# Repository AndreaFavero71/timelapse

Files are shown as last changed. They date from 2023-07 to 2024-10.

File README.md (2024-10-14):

# Timelapse system with Raspberry Pi 4b and PiCamera V3 (wide)

#### timelapse system based on Raspberry Pi 4b and PiCamera V3 wide

The Picamera V3 has interesting characteristics, like auto-focus and HDR;<br />
It comes with Horizontal field of view (102 degrees) or normal (66 degrees), eventually without IR filter (noIR version).<br />
My choice went for the wide version, to have a larger FoV.<br />
<br /><br />

## Purpose
My intention has been documenting the people approaching my CUBOTino booth, at Hannover Maker Faire 2023.<br />
Anyhow, by testing the system on sunrise and sunset, I was already rewarded by this project.<br />

https://github.com/AndreaFavero71/timelapse/assets/108091411/2fbdf898-6a90-448d-a211-95300df74fcc

Hannover Maker Faire 2023: [2 days in 2 minutes](https://youtu.be/wAfPYTDUh8o)<br />
Sunrise and sunset [examples](https://youtu.be/wO7wYDtcbZA)<br />

<br /><br /><br /><br />

## 3D print cover with the camera support
The timelapse system has connection for tripod:<br />
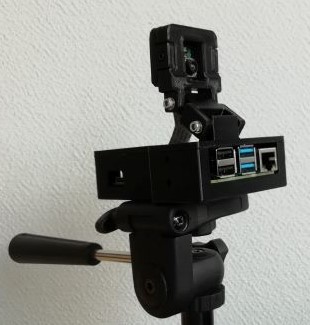
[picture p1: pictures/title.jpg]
title image
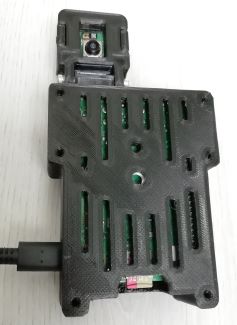
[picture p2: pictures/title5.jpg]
title image
   <br />

and adjustable camera orientation with storage for the camera ribbon cable:<br />
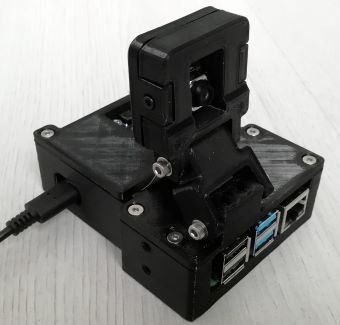
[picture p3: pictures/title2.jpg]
title image
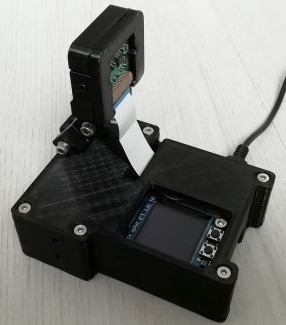
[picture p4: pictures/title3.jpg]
title image
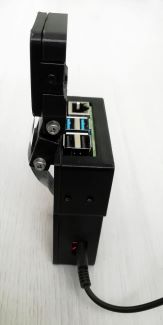
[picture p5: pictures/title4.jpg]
title image
     
<br /><br />
The camera is supported via an arm to vary its orientation, when not used on a tripod with moving head.<br />
Two holes at the cover sides can be used for other fixing systems (i.e. for brackets with suction caps to suspend the system on a window).<br />
Stl file are available at folder [/stl](/stl/).<br /><br /><br />

## Installation
For the installation the needed steps are listed in the [installation file](/setup/installation_steps.txt).
<br /><br /><br /><br />

## How it works
The overall idea is to predefine the job, let it go, and collect the assembled movie once the job is done.<br />
The system is based on a python script and a text file for the settings (the only file to be edited).<br /><br />

The [settings.txt](settings.txt) file includes:
- shooting start (hh:mm).
- shotting stop (hh:mm).
- interval between shoots (seconds).
<br /><br />

Other options are:
- Start shooting immediately (true/false).
- VNC preview (true/false).
- Camera resolution.
- HDR (High Dinamic Range) function at camera (true/false).
- Erasing older pictures from the microSD card that includes emptying the Wastebasket (true/false); This is done at the starting of a new job.
- Auto video generation after the shooting (true/false); this can be based on:
  - predefined fps (frame per second value.
  - predefind video time (in seconds), and the fps will be consequently adapted; For this choice fix_movie_t (true/false) and movie_time_s (seconds).
- Number of shooting days (integer), for the period defined by start and stop time.
- Folder name where saving the pictures and generating the movie.
- Usage of the display at Raspberry Pi (true/false).
- Some parameters for the display, like width, height, horizontal and vertical shif, orientation.<br />

### Notes:
1. Boolean variables can be set as true/false or 1/0 or yes/no or.... .<br />
2. In case the movie is not sattisfactory: Via the script video_render.py the video can be (re)made by changing some parameters. For this reason, the pictures aren't automatically erased after a job completion; pictures are automatically erased at the start of a new job.<br />
3. I found convenient to share a Raspberry Pi folder via SMB protocol, allowing quick access via a pc. For this reason, the pictures_folder is generated in the shared folder. The [installation file](/setup/installation_steps.txt) gives instructions also for this function.

A resume picture of the setting is available [here](https://github.com/AndreaFavero71/timelapse/blob/main/pictures/settings.png) <br />
More info at [instructable page of this project](https://www.instructables.com/Timelapse-With-Raspberry-Pi-4b-and-PiCamera-V3-wid/) <br />
<br /><br /><br /><br />

## Usage:
1. Switch on the Raspberry Pi.<br />
2. Connect to it; If you want a camera preview, a remote desktop connection is necessary like VNC Viewer.<br />
3. The relevant files are into the timelapse folder: ```cd timelapse```<br />
4. Edit the settings.txt file (quite self explanatory) and set the parameters according to your needs: ```nano settings.txt``` (save the file, with Ctrl + X, followed by Y, followed by Enter)<br />
5. Run the script: ```python timelapse.py``` (changes at the settings are only loaded at the scrip start). Arguments can be passed.<br />
6. The code defaults to V2 camera. If you use the V3 camera, add v3_camera argument: ```python timelapse.py --v3_camera```

Feedbacks on the display:<br />
- At the start it shows the main settings, including an estimation of pictures quantity the microSD can store<br />
- Time left for the first picture<br />
- After the first picture is taken, it indicates the picture progressive number<br />
- After the last picture is taken, if set, it indicates the video editing status<br />

In case the movie is not sattisfactory: Via the script video_render.py the video can be (re)made by changing some parameters. For this reason, when set, the pictures aren't automatically erased after a job completion; pictures are automatically erased at the start of a new job.<br />
By pressing one of the buttons for 5 seconds the cycle is stopped<br />
By pressing one of the buttons for more than 10 seconds the script is quitted; If the automating shut-off is set, this is the way to safely close stuff before unpowering the Raspberry Pi.<br />
<br /><br /><br /><br />

## Different methods defining the shooting approach:<br />
1) Shooting predefined between start_hhmm and stop_hhmm, for one or multiple days:<br />
- Set start_now as False and local_control as False.<br />
- Set start_hhmm and stop_hhmm to define the shooting period.<br />
- This method ends automatically, once the stop_hhmm of the last day is reached.<br /><br />

2) Shooting starting once the script is launced (eventually automated at the Raspberry Pi boot), and lasting for the period_hhmm:
- Set start_now as True and local_control as False.<br />
- Set period_hhmm to define how long the shooting period should last.<br />
- Also in this case the pictures quantity are predefined.<br />
To extend the shooting over days, weeks, etc, more than 2 digits can be set at the hours of period_hhmm (i.e. set '1000:30' to shoot for 1000 hours and 30 minutes).<br /><br />

3) By manually starting and pausing the shooting, eventually multiple times, via the buttons on the display:
- Set local_control as True.
- In this case the pictures quantity aren't predefined.
In all cases:
  - The interval between shots is defined by interval_s
  - A long press (>10 secs), of one of the buttons, will terminate the shooting and the script.

<br /><br /><br /><br />

## Automatic script starting at Boot
1. Edit the crontab: sudo crontab -e
2. Add at the end:
```
@reboot /bin/sleep 5; bash -l touch /home/pi/timelapse/timelapse_terminal.log && chmod 777 &_
```
```
@reboot /bin/sleep 5; bash -l /home/pi/timelapse/timelapse_bash.sh > /home/pi/timelapse/timelapse_terminal.log 2>&1
```
3. Save and exit: Ctrl + X, followed by Y, followed by Enter.<br />

After Raspberry Pi boots, the timepse.py script will be excuted according to parameters saved at [settings.txt](settings.txt) file.<br />
Note: To prevent the script from executing at boot, edit the crontab, comment out the two commands and save.
<br /><br /><br /><br />

## Recovery from power outage
This is especially relevant when the system is used for long periods, and power outage might happens. <br />
1. Set the automatic scrip to start at Boot. <br />
2. Set "date_folder" : "False" <br />
3. Set "erase_pics" : "False" <br />

After the power outage, Raspberry Pi boots and the code checks for the latest picture suffix as reference for the next new picture.<br />
In case of multiple days shooting, the days already covered by shooting (partially or fully) are counted (full days without power are also counted). Counted days are detracted from the total days set in settings, to complete the shooting as per schedule.
<br /><br /><br /><br />

## Shooting when enough illuminance
The illuminance estimation by the camera can be used to avoid shooting if illuminance is below a threshold. <br />
1. Set "lux_check" : "True"   (Default is False). <br />
2. Set "lux_threshold" : "30" (30 is about the illuminance at sunset/sunshine. Check [Wikipdia](https://en.wikipedia.org/wiki/Illuminance) for values reference. <br />

When "lux_check" is set False the code doesn't check the illuminance estimation by the camera. <br />
When "lux_check" is set True, and illuminance drops below "lux_threshold", the pictures aren't taken. In this case less pictures are saved while the shooting schedule is safeguarded. <br />
As example of "lux_threshold": "30":<br />
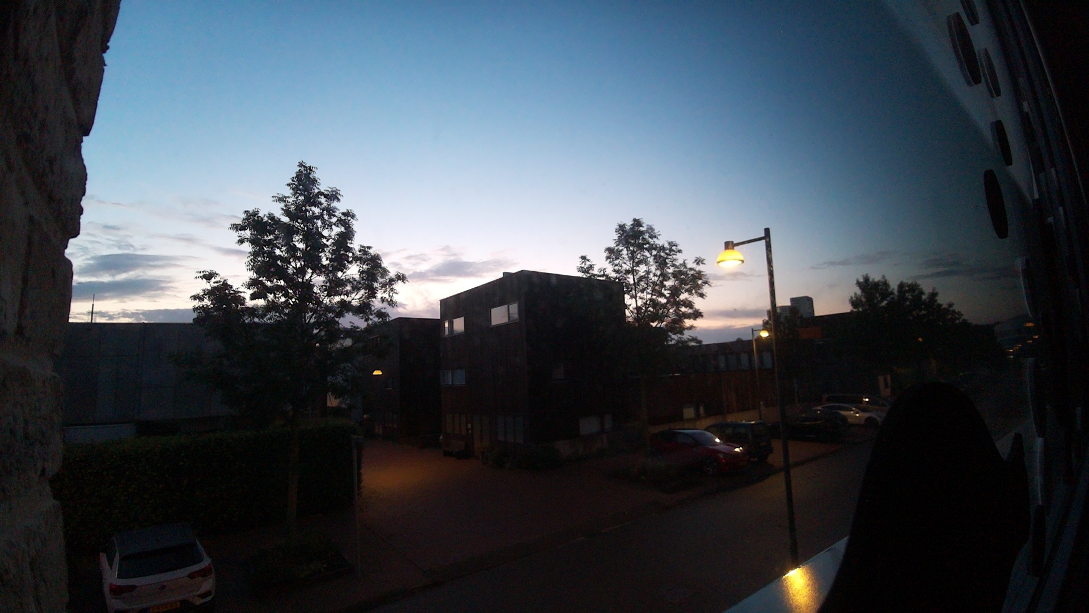
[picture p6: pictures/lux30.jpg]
  <br />
Make your own check on which threshold fits your setup.
 <br /><br /><br /><br />

## Parts
Total cost of the project is ca 130€ (plus shipments) <br />
- 1x [Raspberry Pi 4b](https://www.raspberrypi.com/products/raspberry-pi-4-model-b/) (ca 59€) <br />
- 1x [Picamera V3 Wide](https://www.raspberrypi.com/products/camera-module-3/) (ca 42€) <br />
- 1x [Power supply](https://www.raspberrypi.com/products/type-c-power-supply/) (ca 10€) <br />
- 1x [Display Mini PI TFT 1.3"](https://www.aliexpress.com/item/1005001746881831.html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) (ca 5€ at Aliexpress.com) <br />
- 1x microSD V30 32Gb or higher (ca 10€) <br />
- Screws (see [screws list](/stl/screws_list.txt)) <br />
- Filament for the 3D printer <br />
<br /><br /><br />

## More info:
A resume picture of the setting is available [here](https://github.com/AndreaFavero71/timelapse/blob/main/pictures/settings.png) <br />
More info at [instructable page of this project](https://www.instructables.com/Timelapse-With-Raspberry-Pi-4b-and-PiCamera-V3-wid/) <br />
<br /><br /><br />

## Possible improvements
1. Increase and improve feedback via the display (it's still quite under used).
2. I'm open for your suggestions.
<br /><br /><br />

## Credits and references
[Carolin Dunn](https://github.com/carolinedunn/timelapse/tree/master) tutorial on timelapse.<br />
[Daniel Kendell](https://www.youtube.com/watch?v=ofozNWdIDow) tutorial on overlapping text with ffmpeg.<br />
[TroubleChute](https://www.youtube.com/watch?v=8QxJWW0mjAs) tutorial for Raspberry Pi folder sharing via SMB protocol.<br />
[ffmpeg documentation](https://ffmpeg.org/documentation.html).<br /><br />

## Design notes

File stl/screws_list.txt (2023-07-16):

Timelapse: List of screws, nuts, washers

1x 1/4"-20 UNC  (nut with thread for tripods, to press into the hexagonal slot at the Base, see "Nut_at_Base.jpg" at /pictures)
4x M2.5x5mm (Raspberry Pi to Base)
4x M3x14mm cylindrical head (Arm to Base and camera-support to Arm, see "M3_nuts_washers.jpg" at /pictures)
4x M3 nuts (Base and Arm, see "M3_nuts_washers.jpg" at /pictures)
8x Washers for M3 (in between Arm to Base, between camera-support to Arm, underneath M3 bolts, see "M3_nuts_washers.jpg" at /pictures)
2x M2.5x4mm (Camera_cover to Camera_support)
1x M3x8mm cylindrical head (as display foot, see "display_foot1.jpg" and "display_foot2.jpg" at /pictures)
2x M3 nuts (as display foot, see "display_foot1.jpg" and "display_foot2.jpg" at /pictures)
3x Washers for M3 (underneath the external nut, see "display_foot1.jpg" and "display_foot2.jpg" at /pictures)
6x M3x8mm conical head (Cover to Base)

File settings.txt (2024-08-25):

{
"preview": "False",
"erase_pics": "True",
"erase_movies": "True", 

"local_control": "False",
"start_now": "True",
"period_hhmm": "01:00",
"start_hhmm": "10:00",
"end_hhmm": "12:00",
"interval_s": "20",
"days": "1",

"rendering": "True",
"fix_movie_t": "True",
"movie_time_s": "20",
"fps": "24",
"overlay_fps": "False",
"overlay_text": "",

"camera_w": "1920",
"camera_h": "1080",
"hdr": "True",
"autofocus": "True",
"focus_dist_m": "0.1",
"lux_check": "False",
"lux_threshold": "30",
"date_folder": "True",
"folder": "timelapse_pics",
"parent_folder": "/home/pi/shared",
"pic_name": "picture",
"pic_format": "jpg",
"rotate_180": "False",

"display": "True",
"modified_disp": "False",
"disp_preview": "False",
"disp_image": "False",
"disp_rotation": "90",
"disp_bright": "100",
"disp_width": "240",
"disp_height": "240",
"disp_offsetL": "0",
"disp_offsetT": "0"
}

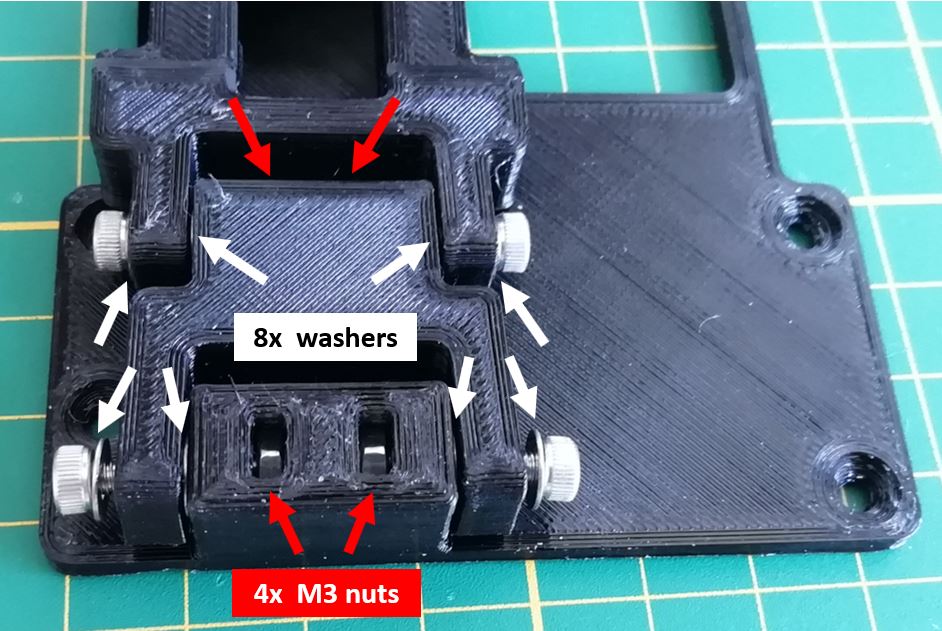
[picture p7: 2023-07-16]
pictures/M3_nuts_washers.jpg

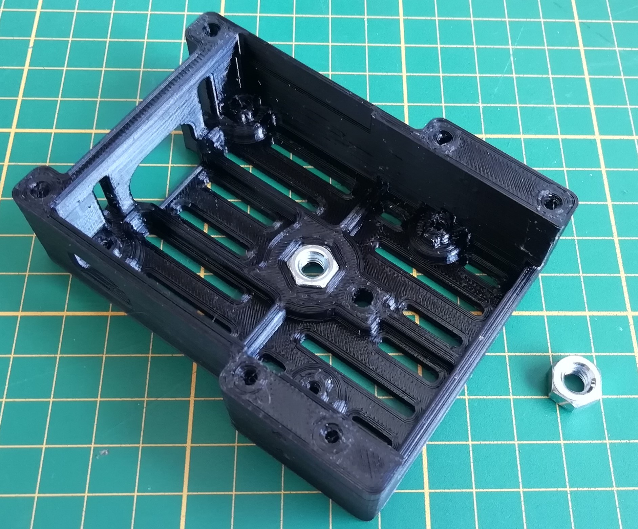
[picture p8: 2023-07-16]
pictures/Nut_at_Base.jpg

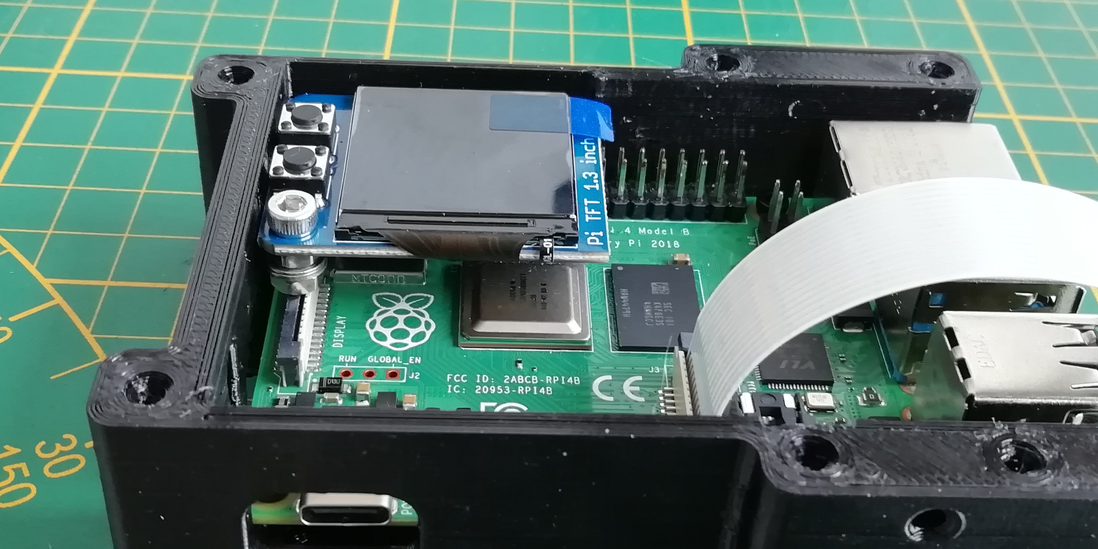
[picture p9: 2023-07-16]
pictures/display_foot2.jpg

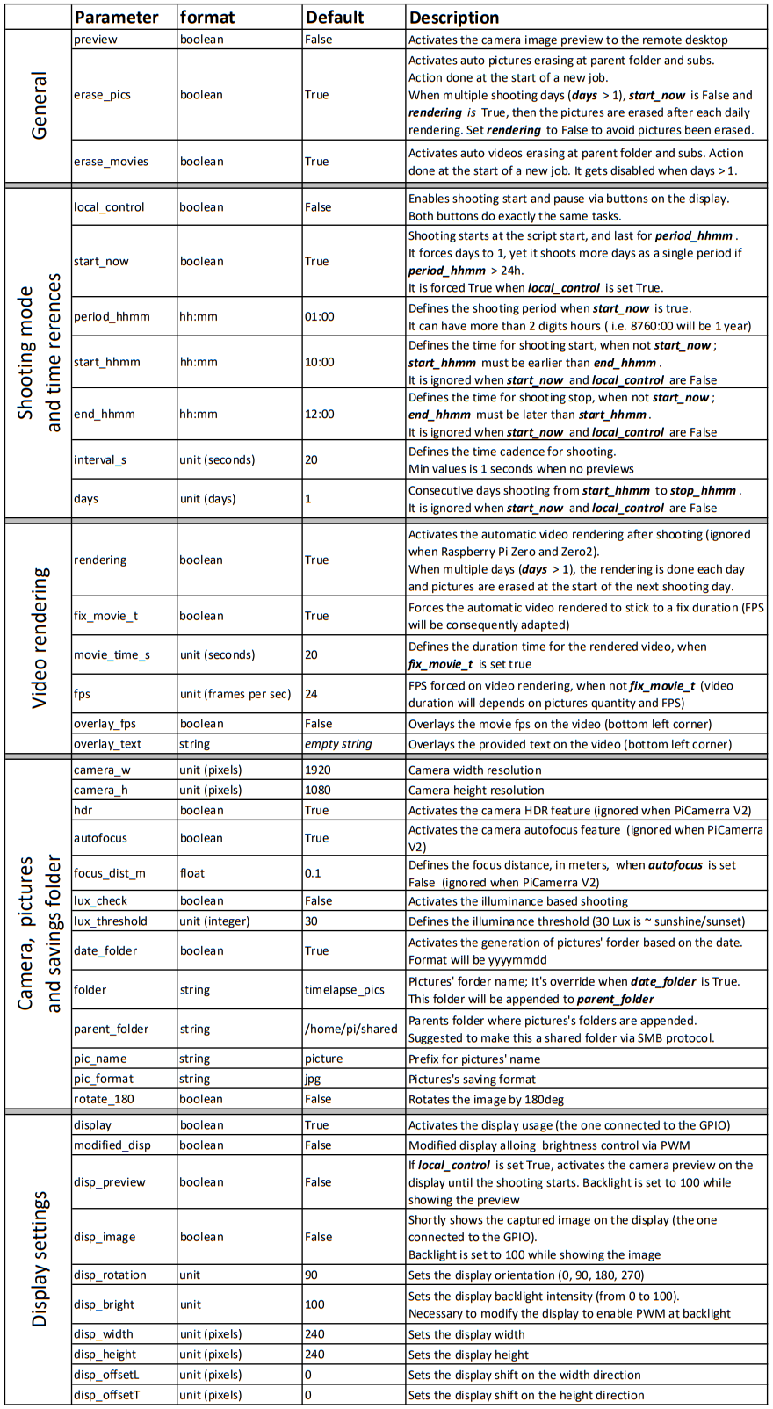
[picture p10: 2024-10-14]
pictures/settings.png

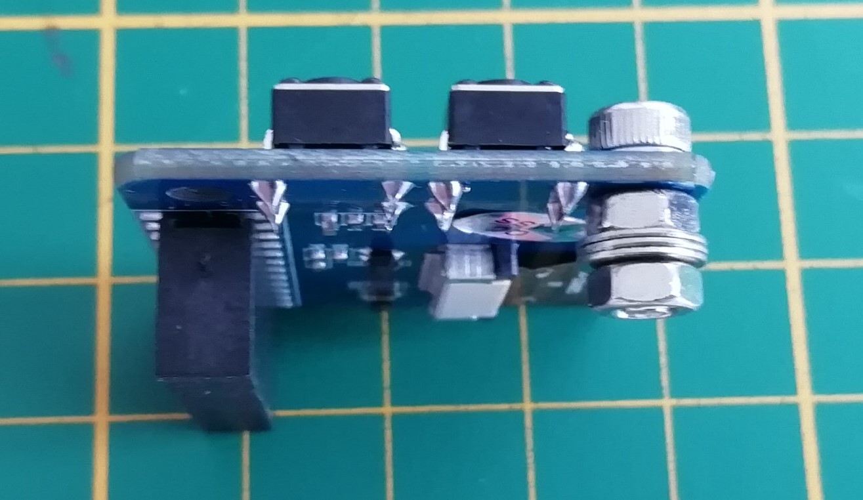
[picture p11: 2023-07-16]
pictures/display_foot1.jpg

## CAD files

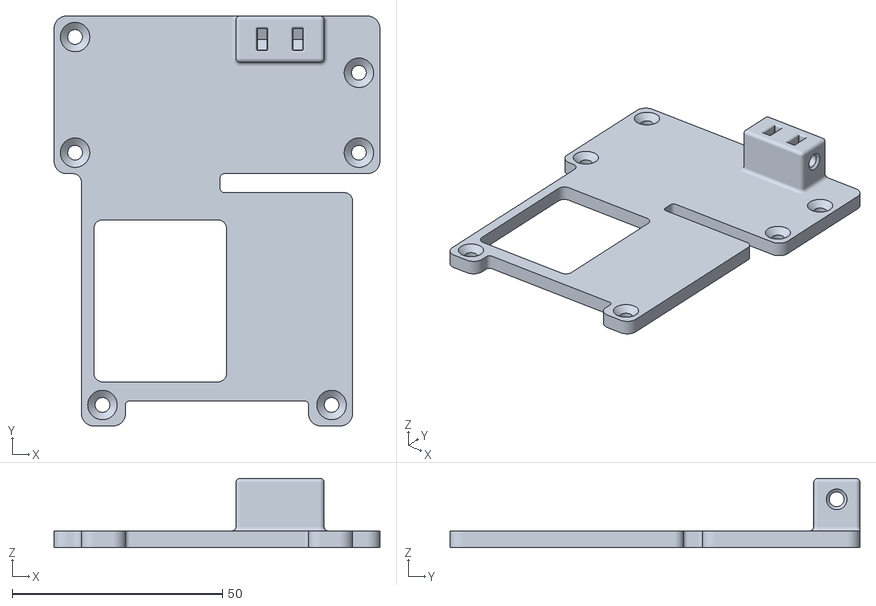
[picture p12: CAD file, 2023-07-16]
stl/Cover.stl
77.5 x 97.5 x 16.5

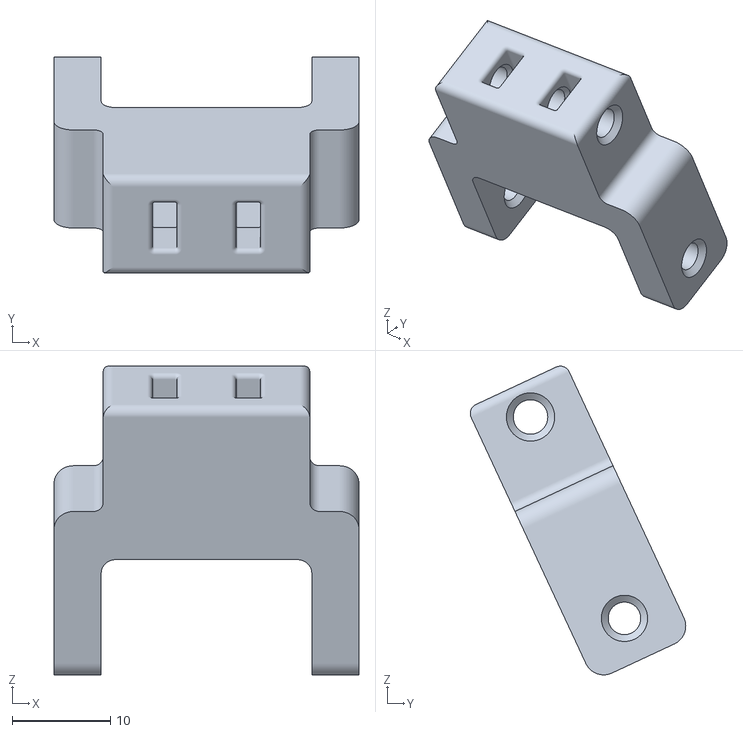
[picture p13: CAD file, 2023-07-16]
stl/Arm.stl
31.0 x 21.9 x 31.4

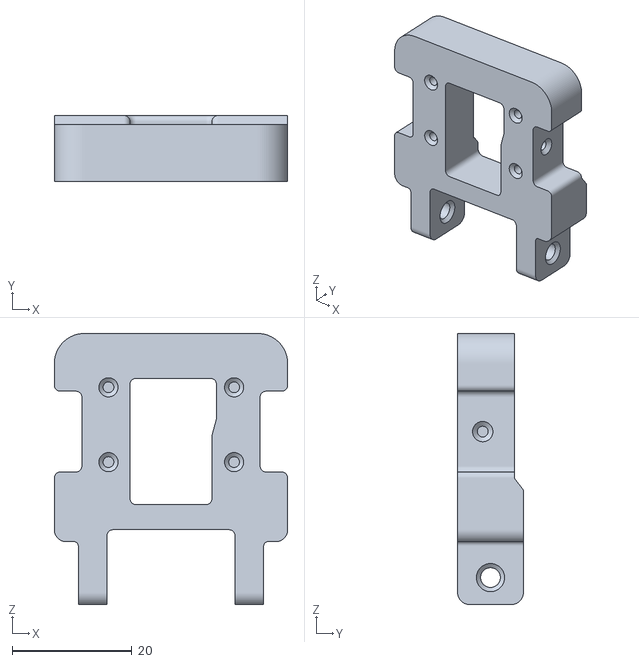
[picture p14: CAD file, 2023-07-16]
stl/Camera_supp.stl
39.0 x 11.0 x 45.3

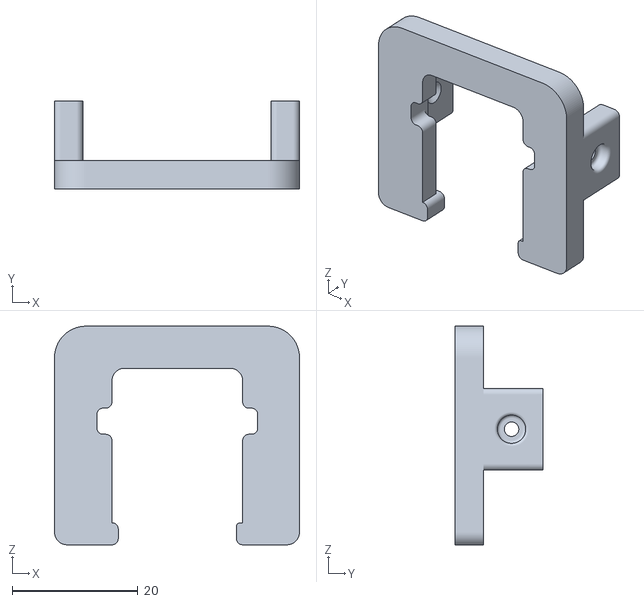
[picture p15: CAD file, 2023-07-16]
stl/Camera_cover.stl
39.0 x 14.0 x 34.8

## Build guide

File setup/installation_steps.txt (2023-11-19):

Setting up the Timelapse:
1. Flash bullseye OS (32 bit) in a fast (V30) microSD card, via Raspberry Pi Imager or other imager tool.
1.1 It is convenient to set a meaningfull Hostname (i.e. timelapse).
1.2 For convenience with the script, leave Username as "pi", while you're invited to set your own password (do not use the raspberry as password).
1.3 Configure the LAN from which you're going to initially connect (i.e. via SSH).
2. Into the boot folder copy the wpa_supplicant.conf text file with included the wi-fi connections you might need (phone AP is a convenient one); An example of this file if provided as reference, to be personalized with your Country digits, the Wi-Fi SSID and Passwords.
3. Into the boot folder make an empty text file named ssh (without extention).
4. Insert the microSD into the Raspberry Pi, power on and wait until the green LED stops blinking.
5. Check for the Raspberry Pi IP in your network.
6. Connect to the Raspberry Pi via SSH (i.e. via Putty).
7. Update the system: sudo apt update
8. Upgrade the system: sudo apt upgrade -y
9. Install the picamera library (it should be already installed): sudo apt install python3-picamera2
10. Install the driver for the display: sudo pip3 install ST7789==0.0.4
11. Enable the SSH, SPI, VNC and VNC Display resolution: sudo raspi-config
11.1 Select: Interface Options
11.2 Select: SSH   (then YES)
11.3 Select: Interface Options
11.4 Select: SPI   (then YES)
11.5 Select: Interface Options
11.6 Select: VNC   (then YES)
11.7 Select: Display Options
11.8 Select: VNC Resolution (choose the one tha better suit your PC monitor, then OK)
11.9 Select: Finish
11.10. Confirm the reboot with YES (if you miss it, from the terminal type: sudo reboot)
12. Connect via VNC (i.e. via realVNC)
13. Open the Terminal (this step can be done from step 7)
14. Clone the repository: git clone https://github.com/AndreaFavero71/timelapse.git (this step can be done from step 7)

Making a shared folder via SMB protocol:
1. Install samba; From the Terminal: sudo apt install samba samba-common-bin (confirm with y, and yes at DHCP package wins)
2. Make the folder to share: mkdir /home/pi/shared
3. Edit samba config file: sudo nano /etc/samba/smb.conf    (at the file end add the below 6 rows, Ctrl + Ins to paste)
[shared]
path=/home/pi/shared
writeable=yes
create mask=0777
directory folder=07777
pubblic=no
4. Save and close the samba config file: Ctrl+X then Y then Enter
5. Associate your username: sudo smbpasswd -a pi    (pi is the username)
   once requested enter your password (the one to access the Raspberry Pi)
   once requested enter your password again (the one to access the Raspberry Pi)
   at this point there should be a confirmation "Added user pi."
6. Restart smb service: sudo systemctl restart smbd
7. Get the Raspberry Pi IP: hostname -I  (capital I)
8. On your File Explorer Adress bar paste the IP, after the prefix "\\" and followed by the postfix "\shared": \\xx:xx:xx:xx\shared
9. Enter the password, and check it to get memorized.
10. The Raspberry Pi "shared" folder should be visible as a network folder; map it as a drive for convenience.

Test / usage
1. The timelapse files are under 'timelapse' folder: cd timelapse
2. Edit the settings.txt file, set it for a couple of minutes shooting, and save it: nano settings.txt  (Ctrl + X  then Y  then Enter)
3. Run the timelapse script: python3 timelapse.py
4. If the preview is enabled, an additional windows opens with the Picamera preview live streaming.
5. Check into the generated folder at /home/shared/  for the captured pictured and the generated timelapse movie.

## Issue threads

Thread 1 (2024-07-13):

Error and fix to use a Picamera V2 instead of V3

mharmuth, 2024-07-13:
First of all: Thank you for this great project!

I got a little error when trying to execute the script. I've got a Raspberry Pi4 Model B with the Pi camera module V2.
`python3-pycamera2` is installed and working (I tested it with an example script from the project).

But when I try to run your script, I get the following log
```
pi@pios:~/timelapse $ python3 timelapse.py

Processor architecture: aarch64

[1:17:28.995680973] [5916]  INFO Camera camera_manager.cpp:313 libcamera v0.3.0+65-6ddd79b5
[1:17:29.021947286] [5919]  WARN RPiSdn sdn.cpp:40 Using legacy SDN tuning - please consider moving SDN inside rpi.denoise
[1:17:29.023584068] [5919]  WARN RPI vc4.cpp:392 Mismatch between Unicam and CamHelper for embedded data usage!
[1:17:29.024210767] [5919]  INFO RPI vc4.cpp:446 Registered camera /base/soc/i2c0mux/i2c@1/imx219@10 to Unicam device /dev/media4 and ISP device /dev/media1
[1:17:29.024254303] [5919]  INFO RPI pipeline_base.cpp:1104 Using configuration file '/usr/share/libcamera/pipeline/rpi/vc4/rpi_apps.yaml'
[1:17:29.026548765] [5916]  INFO Camera camera_manager.cpp:313 libcamera v0.3.0+65-6ddd79b5
[1:17:29.051271480] [5922]  WARN RPiSdn sdn.cpp:40 Using legacy SDN tuning - please consider moving SDN inside rpi.denoise
[1:17:29.052839967] [5922]  WARN RPI vc4.cpp:392 Mismatch between Unicam and CamHelper for embedded data usage!
[1:17:29.053406703] [5922]  INFO RPI vc4.cpp:446 Registered camera /base/soc/i2c0mux/i2c@1/imx219@10 to Unicam device /dev/media4 and ISP device /dev/media1
[1:17:29.053443869] [5922]  INFO RPI pipeline_base.cpp:1104 Using configuration file '/usr/share/libcamera/pipeline/rpi/vc4/rpi_apps.yaml'
[1:17:29.060032979] [5916]  INFO Camera camera.cpp:1183 configuring streams: (0) 1920x1080-XBGR8888 (1) 640x360-YUV420 (2) 1920x1080-SRGGB10_CSI2P
[1:17:29.060428680] [5922]  INFO RPI vc4.cpp:621 Sensor: /base/soc/i2c0mux/i2c@1/imx219@10 - Selected sensor format: 1920x1080-SRGGB10_1X10 - Selected unicam format: 1920x1080-pRAA
unknown control 'wide_dynamic_range'
  HDR setting returned an error

Failing to close the Picamera
Failing to clean the display
Failing to set low the GPIO pin 22
Traceback (most recent call last):
  File "/home/pi/timelapse/timelapse.py", line 1183, in <module>
    variables, error = setup()             # retrieves settings, and initializes things
                       ^^^^^^^
  File "/home/pi/timelapse/timelapse.py", line 256, in setup
    picam2, camera_started, error = set_camera(camera_w, camera_h, rotate_180, hdr, autofocus, focus_dist_m, preview)
    ^^^^^^^^^^^^^^^^^^^^^^^^^^^^^
TypeError: cannot unpack non-iterable float object

During handling of the above exception, another exception occurred:

Traceback (most recent call last):
  File "/home/pi/timelapse/timelapse.py", line 1185, in <module>
    exit_func(error)                       # exit function is caleld
    ^^^^^^^^^^^^^^^^
  File "/home/pi/timelapse/timelapse.py", line 1134, in exit_func
    if display:
       ^^^^^^^
NameError: name 'display' is not defined
```

Here is my `settings.txt`:
[settings.txt](https://github.com/user-attachments/files/16202125/settings.txt)

I don't know what the error can be. Maybe you can help ;-)

AndreaFavero71, 2024-07-13:
This code has been writtren for the Picamera V3.
The camera V2 does't have some of features of the V3 model, like autofocus and HDR, and errors are generated when trying to set the parameters for those features.

A possible fix:
1) at timelapse.py comment out rows from 334 to 343 included.
2) set false the parameters autofocus and HDR in the settings.txt (as per yourr current settings).
.... and the script will be compatible with the V2 camera (I have just tried).

Please be aware:
1) the PiCamera V2 has fix focus, that can only be manually adjusted.
2) the HDR is really a worth feature, especially when the subject is partially shadowed.
Of course it depends from your application, if the autofocus (that also means you can set a fix focus to a given distance via the settings) and the HDR are usefull or not.

mharmuth, 2024-07-15:
Hi @AndreaFavero71,

thanks for your help. I can confirm that it's working with the rows commented out. Thanks again!

But I will go and grab the PiCamera V3 to have the additional features.

Closed 2024-07-15.

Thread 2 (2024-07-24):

Construction Cam

weedy171, 2024-07-24:
Love the project. Not really an issue, but wondering if you have any suggestion in setting it up so it only records during the daylight between sunrise and sunset. I would like to use your project for a small construction project that is going to last about 3 months.

Thanks !

AndreaFavero71, 2024-07-26:
Hi, the code Is not linked with a calendar, therefore it isn't possible to start shooting at sunrise and stop at sunset.
The code accepts a start time, a stop time, and eventually the number of days to repeat the shooting between start and stop.
During the construction, I would recommend to approach the Raspberry Pi from time to time, and discharge the pictures or the video clips. This to backup the data, preventing total loss in case of a any issue, for instance the microSD getting corrupted.

weedy171, 2024-07-28:
Appreciate the suggestions. I did find a script that will look at images and determine if they are black. I think I am having some trouble though with my settings. I am hoping to set my timelapse to run every day and take a picture at 600 seconds for three months. I was thinking about rebooting the device nightly as well(or might change it to the week) Thinking about recovery if a power outage was to occur and where it could pick up where its at.

{
"preview": "False",
"erase_pics": "False",
"erase_movies": "False",

"local_control": "False",
"start_now": "True",
"period_hhmm": "01:00",
"start_hhmm": "00:01",
"end_hhmm": "23:59",
"interval_s": "600",
"days": "120",

"rendering": "False",
"fix_movie_t": "False",
"movie_time_s": "20",
"fps": "24",
"overlay_fps": "False",
"overlay_text": "",

"camera_w": "1920",
"camera_h": "1080",
"hdr": "True",
"autofocus": "True",
"focus_dist_m": "0.1",
"date_folder": "True",
"folder": "timelapse_pics",
"parent_folder": "/home/weedy/shared",
"pic_name": "picture",
"pic_format": "jpg",
"rotate_180": "False",

"display": "True",
"modified_disp": "False",
"disp_preview": "False",
"disp_image": "False",
"disp_rotation": "90",
"disp_bright": "100",
"disp_width": "240",
"disp_height": "240",
"disp_offsetL": "0",
"disp_offsetT": "0"
}

AndreaFavero71, 2024-07-28:
Hi, getting the code starting automatically at the boot is rather easy, I'll follow up.
The current code is not meant to restart from where it left, but it makes a lot of sense in case of power outage.
Once back from holiday I'll  modify the code.
When is the construction going to start?
When will you have the setup ready for testing?

Considering the expected large variation of light condition, strongly suggested a camera with HDR function, so the V3 normal or the V3 wide.

Also recommended to set a couple of wifi addresses at the Raspberry Pi, one of them with your laptop hotspot (Windows allows it if the PC has a wifi connection, that could be to your phone hotspot)

For the settings, there is a bit more explanation  at the Instructables project [page](https://www.instructables.com/Timelapse-With-Raspberry-Pi-4b-and-PiCamera-V3-wid/).
Considering your scope, I'd set start_hhmm when the daily activities are expected to start, let say 0700. Similarly, the stop__hhmm when the daily activities are supposed to stop, let say 1900.
I'd also reduce the interval_s to 300 seconds, and eventually double the frames per second of the video clip, for a smoother result. Total quantity of images are still manageable, so the memory.
I have a few more notes about settings, but those will come later

weedy171, 2024-07-29:
Thanks again for your replies.
My construction project is starting the end of next month. I was starting to play around with it to get a feel for the size of pictures and how often I would need to get grab them and how well it would work on recovery of power loss if their was any(don’t have a way to put a UPS outside)

I am using this camera https://www.adafruit.com/product/5658 -- I tried a higher resolution 4608 × 2592 pixels but it was not happy about that.

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

AndreaFavero71, 2024-07-29:
Hi, that camera supports the HDR (strongly suggested to use it) by reducing the resolution to the HD format. Depending on the subject, the JPG file might take from 250Kb (large uniform areas) to 600Kb (small uniform areas).
I believe, by mid of August, I'll be able to add the info for the automatic start after booting, and the code change to proceed with pictures' names from where it was before an eventual power outage....

weedy171, 2024-08-08:
Thanks for looking into this while you are on holiday. I updated the latest py and updated my settings to the following. I noticed it created the folder "timelapse_pics" inside my shared but don't see any pictures in it. I was able prior to get the autostart the py while and the old py was generating images.

{
"preview": "True",
"erase_pics": "False",
"erase_movies": "False",

"local_control": "False",
"start_now": "False",
"period_hhmm": "8760:00",
"start_hhmm": "06:00",
"end_hhmm": "19:00",
"interval_s": "180",
"days": "120",

"rendering": "False",
"fix_movie_t": "False",
"movie_time_s": "20",
"fps": "24",
"overlay_fps": "False",
"overlay_text": "",

"camera_w": "1920",
"camera_h": "1080",
"hdr": "True",
"autofocus": "True",
"focus_dist_m": "0.1",
"date_folder": "False",
"folder": "timelapse_pics",
"parent_folder": "/home/weedy/shared",
"pic_name": "picture",
"pic_format": "jpg",
"rotate_180": "False",

"display": "False",
"modified_disp": "False",
"disp_preview": "False",
"disp_image": "False",
"disp_rotation": "90",
"disp_bright": "100",
"disp_width": "240",
"disp_height": "240",
"disp_offsetL": "0",
"disp_offsetT": "0"
}

AndreaFavero71, 2024-08-08:
Hi, when the code is started at the boot (crontab), all the prints will be
saved in the text file timelapse_terminal.log.

Everytime the Raspberry Pi boots, the same file will be used (over written)
Please boot the system again, and check the content of that file within the
expected shooting period of the day.
In case or errors indications, share the complete file to
***@***.***
Perhaps good to share it anyhow.

I'm going to be driving the coming days, therefore I'll be rather limited
... yet good for me to start thinking what goes grong and why.

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

weedy171, 2024-08-08:
I just checked this morning and it started taking pictures at the start period.  I will have to play with it later in the day to see if a reboot of the device makes it still work.

weedy171, 2024-08-09:
I think I figured it out, I had the end time set earlier in the night compared to when i was working on the script. It appears to be working. I will play around with it some more. Do you think the resolution I have set could be any better or you think that is good for the Camera 3?

AndreaFavero71, 2024-08-09:
Hi, sounds good.
1920x1080 is the max resolution for the V3 camera, when HDR is set True.
The video clip will be HD.
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
AndreaFavero71, 2024-08-15:
Hi, after a power outage, the code is started automatically at the boot, and if you reconnect to the Raspberry Pi you won't see the prints made by code to the terminal ... yet prints are redirected to a text file: /timelapse/timelapse_terminal.log (this is what I meant as "terminal.log file").
So you can open that text file, to see what kind of feedback the code is printing out, further than checking the timestamp of the pictures in folder.

Be aware the boot takes a couple of minutes and the first picture will be taken at about the next minute chance; When waiting, without doing anything lse, this time seems even longer and it might let you think the code not being active ....
Having the mini display on the Raspberry Pi makes life easier :-)

On the tests I performed, everything was working fine.
Overall, I have hard time to follow the chain of events at your end, I'm afraid it requires more detailed and clear info from you.

weedy171, 2024-08-16:
Thanks for the replies. I was playing around with it tonight and doing a couple of power outage simulations and do not see the same results like I reported prior. I haven’t had a chance to play around with the daylight setting. I might just leave it alone. I plan on checking the camera at least once a week and grab the pictures and feel comfortable with what I have setup. Appreciate the code fix and the contributions for this project. I know some linux stuff but I am not around it lot, so its fun to play around this stuff too.

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

AndreaFavero71, 2024-08-21:
Hi, I think I've discovered the reason we have different results after recovering from a power outage.
Background: The timing methd used to take the pictures is based on the EPOCH time, to prevent shifting over time.
In my case, once the Pi boots it will also find a network and an NTP (Network Time Protocol) and this might not be always the case or your case.
When the Pi boots and does not find a NTP, the internal clock proceeds from where it left: The pictures won't be taken as per intended schedule.

To overcome this issue, I see two options:
1) Adding a RTC module, with backup battery, to the the Pi (i.e. search for 'DS3231 Real Time Clock Module RTC Clock Memory Module 3.3V/5V for Raspberry Pi').
2) Changing the shootting approach (settings) to "start_now": "True" with a very long period "period_hhmm": "3000:00"  (covers 125 days) and by bounding the shooting to the illuminance level.

**Option 1** is rather clean yet, further than the hardware, it requires to properly set the Pi in order to use the hardware clock after a power outage. Time alignment with NTP happen once the Pi will connect to a network. I don't have personal experience with these modules. With this option the pictures time stamp are always correct.

**Option 2** should work too, yet with some caviets. In case of power outage and booting without a network available (no NTP), the pictures will be tken as per interval_s and Lux but the timestamp will be wrong.

I have now available a Pi with a screen alowing for tests with and without network connection: Tests on option 2 confirms the above notes.

weedy171, 2024-08-21:
I just installed the device last night and noticed the issue of the time changing and I had to manually set it. I will find out in a couple days how things are going.

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

AndreaFavero71, 2024-08-25:
Hi, I've just released an update, that includes:
1) Recovering from power outage also when the shooting approach is based on "start_now" and related "period_hhmm".
2) Moved the "lux_check" and "lux_threshold" to the settings.txt.
3) Some minor improvements.
Wrt your target, I think you'll benefit from setting "start_now" as True, a very long "period_hhmm" (i.e 3000:00 will cover 125 days) and by bounding the shooting to the illuminance level: Set "lux_check" as True and "lux_threshold" to 30.
In case the system is not into a network nor having a RTC module, by setting "start_now" as True and the illuminance control, the shooting  schedule won't mess up in case a power outage will happen.

weedy171, 2024-08-27:
I was able to grab three days worth prior to the start of the construction and everything looked great. Then it appeared it worked for a day after then stopped. I missed two important destruction so kinda bummed about that. Not sure what happened. I tried to implement some of your suggestions below and now I did not see it try to take pictures after a reboot. Can you look at the settings I posted above and make sure I am not missing anything. Do you think because I am not rendering the file that is an issue?

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

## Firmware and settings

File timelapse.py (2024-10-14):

#!/usr/bin/python
# coding: utf-8

"""
#############################################################################################################
#  Andrea Favero 10 October 2024,
#  Timelapse module, based on Raspberry Pi 4b and PiCamera (V2 or V3)
#
#  Last version (addition): Recovery from power outage and shooting when illuminance above threshold
#  Recovery from power outage works when below parameters are set like:
#        "date_folder" : "False" (it points to "folder")
#        "erase_pics" : "False"  (latest picture suffix retrieved to prevent pictures being overwritten)
#  Shooting when illuminance above threshold works when below parameters are set like:
#        "lux_check" : "True"    (it enables lux estimation by the camera)
#        "lux_threshold" : "30"  (sets the lux threshold, 30 is about the illuminance at sanset/sunshine)
#############################################################################################################
"""


# __version__ variable
version = '0.7 (10 Oct 2024)'


################  setting argparser for parameter parsing  ######################################
import argparse

# argument parser object creation
parser = argparse.ArgumentParser(description='CLI arguments for timelapse.py')

# --version argument is added to the parser
parser.add_argument("-v", "--version", help='Shows the script version.', action='version',
                    version=f'%(prog)s ver:{version}')

# --v3_camear argument is added to the parser
parser.add_argument("--v3_camera", action='store_true',
                    help="Enable V3 camera (autofocus and HDR functions")

# --debug argument is added to the parser
parser.add_argument("-d", "--debug", action='store_true',
                    help="Activates printout of settings, variables and info for debug purpose")

# --parent argument is added to the parser
parser.add_argument("--parent", type=str, 
                    help="Input the parent folder name (where to append pictures' folders)")

# --folder argument is added to the parser
parser.add_argument("--folder", type=str, 
                    help="Input the folder name where pictures are saved")

# --render argument is added to the parser
parser.add_argument("--render", action='store_true', 
                    help="Force the video rendering on Rpi Zero and Zero2")

# --skip_intro argument is added to the parser
parser.add_argument("--skip_intro", action='store_true', 
                    help="Does not show introction info on display")

# --fps argument is added to the parser
parser.add_argument("--fps", type=int, 
                    help="Input the video fps (video lenght adapts to this)")

# --time argument is added to the parser
parser.add_argument("--time", type=int, 
                    help="Input video length time in secs (fps adapt to this)")

# --text argument is added to the parser
parser.add_argument("--text", type=str, 
                    help="Input the text to overlay on video. If 'fps' the used value is overlaid")

args = parser.parse_args()   # argument parsed assignement
# ###############################################################################################




# libraries import
from picamera2 import Picamera2, Preview
from libcamera import controls
from os import system
from time import time, sleep, localtime, strftime
from datetime import datetime, timedelta
import os.path, pathlib, stat, sys, json
import RPi.GPIO as GPIO
import subprocess, socket
from subprocess import Popen, PIPE






def to_bool(value):
    """ Converts argument to boolean. Raises exception for invalid formats
        Possible True  values: 1, True, true, "1", "True", "yes", "y", "t"
        Possible False values: 0, False, false, None, [], {}, "", "0", "False", "no", "n", "f", 0.0, ...
    """

    if str(value).lower() in ("yes", "y", "true",  "t", "1"): # case lowercase value string is in the tuple elements
        return True                                   # True is returned
    elif str(value).lower() in ("no",  "n", "false", "f", "0", "0.0", "", "none", "[]", "{}"): # case lowercase value string is in the tuple elements
        return False                                  # False is returned
    print("Issue with settings value:", value)        # case if and elif aren't satisfied
    raise Exception                                   # exception is raised





def check_rpi_zero():
    """ Check if Rpi is ZeroW or Zero2W.
        Some program parts are non executed (i.e. ffmpeg commands) in this case.
    """
    
    import os                                         # os is imported to check the machine
    
    rpi_zero = False                                  # flag for a Zero or Zero2
    try:                                              # tentative approach
        processor = os.uname().machine                # processor is inquired
        print(f'Processor architecture: {processor}')  # print to terminal the processor architecture
        if 'armv6' in processor or 'armv7l' in processor:  # case the string armv6 or armv7l are contained in processor string
            rpi_zero = True                           # flag for program running on Rpi ZeroW
            print('Program adapted for armv6 and armv7l')  # feedback is printed to the terminal
    except:                                           # case an exception is raised
        print("Cannot detect the Raspberry Pi model")
        error = 1                                     # error is set to 1
        exit_func(error)                              # exit function is caleld
    return rpi_zero                                   # boolean rpi_zero is returned





def check_screen_presence():
    """ Checks if a display is connected, eventually via VNC; This is not the (SPI) display at Raspberry Pi."""
    
    import os                                         # os library is imported
    
    if 'DISPLAY' in os.environ:                       # case the environment variable DISPLAY is set to 1 (there is a display)
        if debug:                                     # case debug variable is set True (on __main__ or via argument)
            print('Display function is availbale')    # feedback is printed to the terminal
        return True                                   # function returns True, meaning there is a screen connected
    else:                                             # case the environment variable DISPLAY is set to 0 (there is NOT a display)
        
#################    case of local display at the Raspberry Pi   ###################################
#         try:
#             os.environ['DISPLAY'] = ':0'
#             print("Successfully set os.environ['DISPLAY'] = ':0'")
#         except:
#             print("Failed to set os.environ['DISPLAY'] = ':0'")
# ##################################################################################################
            
        if debug:                                     # case debug variable is set True (on __main__ or via argument)
            print('Display function is not availbale')  # feedback is printed to the terminal
        return False                                  # function returns False, meaning there is NOT a screen connected





def setup():
    """ Reads settings from the settings.txt file and add them in a dictionary.
        Sets the camera, and the display
    """

    variables={}                                      # empty dictionary to store the local variable
    
    screen = check_screen_presence()                  # screen presence is checked (also VNC is accounted)
    rpi_zero = check_rpi_zero()                       # raspberry pi Zero and Zero2 processor check
    
    error = 0                                         # error cose is set to zero (no errors)
    folder = pathlib.Path().resolve()                 # active folder   
    fname = os.path.join(folder,'settings.txt')       # folder and file name for the settings
    if os.path.exists(fname):                         # case the settings file exists
        with open(fname, "r") as f:                   # settings file is opened in reading mode
            settings = json.load(f)                   # json file is parsed to a local dict variable
        
        if debug:                                     # case debug is set True
            print('\n\nSettings.txt content:')        # Introducing the next print to terminal
            for k, v in settings.items():             # iterating over keys values of settings dict
                print(" ", k, ":", v)                 # print the settings
            print('\n\n')                             # print empty lines
        
        try:                                          # tentative approach
            preview = to_bool(settings['preview'])    # flag to show the camera preview to screen (anso VNC)
            erase_pics = to_bool(settings['erase_pics']) # flag to erase old pictures from folder
            erase_movies = to_bool(settings['erase_movies']) # flag to erase old movies from folder
            local_control = to_bool(settings['local_control']) # flag to enable setting changes via UI at Raspberry Pi
            start_now = to_bool(settings['start_now'])  # flag to force shoting immediatly or at set datetime
            period_hhmm = str(settings['period_hhmm'])  # shooting period in hhmm when start_now
            start_hhmm = str(settings['start_hhmm'])  # hh:mm of shooting start time
            end_hhmm = str(settings['end_hhmm'])      # hh:mm of shooting end time
            interval_s = int(settings['interval_s'])  # pictures cadence in seconds (smallest is ca 2 seconds for jpeg and 5 for png)
            days = int(settings['days'])              # how many days the timelapse is made
            rendering = to_bool(settings['rendering'])  # flag for automatic video rendering in Raspberry Pi
            fix_movie_t = to_bool(settings['fix_movie_t'])  # flag for automatic video rendering in Raspberry Pi
            movie_time_s = int(settings['movie_time_s']) # movie duration time
            fps = int(settings['fps'])                # default fps at video generation (when not forced to a fix video time)
            overlay_fps = to_bool(settings['overlay_fps'])  # flag for overlaying the used fps at movie rendering
            camera_w = int(settings['camera_w'])      # camera width in pixels
            camera_h = int(settings['camera_h'])      # camera height in pixels
            hdr = to_bool(settings['hdr'])            # flag for hdr (High Dinamy Range) camera setting
            autofocus = to_bool(settings['autofocus'])   # flag to enable/disable autofocus
            focus_dist_m = float(settings['focus_dist_m'])  # distance in meter for manual focus
            date_folder = to_bool(settings['date_folder'])  # flag to force folder name of current yyyymmdd instead folder name
            folder = str(settings['folder'])          # folder name to store the pictures
            pic_name = str(settings['pic_name'])      # picture prefix name
            pic_format = str(settings['pic_format'])  # picture format
            display = to_bool(settings['display'])    # flag for display usage
            
            
            ##############################################################################
            # additions made after project published at Instructables
            if settings.get('modified_disp') == None: # case modified_disp is not a key in settings.txt 
                instructions_info('modified_disp')    # instructions_info function is called
            else:                                     # case disp_preview is a key in settings.txt
                modified_disp = to_bool(settings['modified_disp'])  # flag to modified display for PWM
            
            if settings.get('disp_bright') == None:   # case disp_bright is not a key in settings.txt 
                instructions_info('disp_bright')      # instructions_info function is called
            else:                                     # case disp_bright is a key in settings.txt
                disp_bright = int(settings['disp_bright'])  # display brightness (allowed 0 to 100)
                disp_bright == 10 if disp_bright < 0 else disp_bright   # display brightness min value set to 10
                disp_bright == 100 if disp_bright > 100 else disp_bright # display brightness max value set to 100
            
            if settings.get('disp_preview') == None:  # case disp_preview is not a key in settings.txt 
                instructions_info('disp_preview')     # instructions_info function is called
            else:                                     # case disp_preview is a key in settings.txt
                disp_preview = to_bool(settings['disp_preview'])  # flag to display preview on the display
            
            if settings.get('disp_image') == None:    # case disp_image is not a key in settings.txt 
                instructions_info('disp_image')       # instructions_info function is called
            else:                                     # case disp_image is a key in settings.txt
                disp_image = to_bool(settings['disp_image'])  # flag to display image on the display
                
            if settings.get('rotate_180') == None:    # case rotate_180 is not a key in settings.txt 
                instructions_info('rotate_180')       # instructions_info function is called
            else:                                     # case rotate_180 is a key in settings.txt
                rotate_180 = to_bool(settings['rotate_180'])  # flag to rotate image of 180deg before saving it
            
            if settings.get('overlay_text') == None:  # case overlay_text is not a key in settings.txt 
                instructions_info('overlay_text')     # instructions_info function is called
            else:                                     # case overlay_text is a key in settings.txt
                overlay_text = str(settings['overlay_text'])  # overlay_text to overlay on video editing
                
            if settings.get('parent_folder') == None: # case parent_folder is not a key in settings.txt 
                instructions_info('parent_folder')    # instructions_info function is called
            else:                                     # case parent_folder is a key in settings.txt
                parent_folder = str(settings['parent_folder'])  # parent_folder name to append folders
            
            if settings.get('lux_check') == None:     # case lux_check is not a key in settings.txt 
                instructions_info('lux_check')        # instructions_info function is called
            else:                                     # case parent_folder is a key in settings.txt
                lux_check = to_bool(settings['lux_check'])  # flag to enable lux_check
            
            if settings.get('lux_threshold') == None: # case lux_threshold is not a key in settings.txt 
                instructions_info('lux_threshold')    # instructions_info function is called
            else:                                     # case parent_folder is a key in settings.txt
                lux_threshold = int(settings['lux_threshold'])  # lux threshold to take or not a picture
                
            # ############################################################################

            
        except:                                       # case of exceptions
            print('Error: Missed parameter at imported parameters') # feedback is printed to the terminal
            print('or bad parameter format resulting in convertion error to bool or int') # feedback is printed to the terminal
            error = 1                                 # error variable is set to 1
            return error                              # error code is returned
   
    else:                                             # case the settings file does not exists, or name differs
        print('Could not find the file: ', fname)   # feedback is printed to the terminal
        error = 1                                     # error variable is set to 1
        return error                                  # error code is returned


    # evaluating and modifying settings due to HW reality
    if preview and not screen:                        # case the preview is set True and screen is not detected
        preview = False                               # preview is changed to False to prevent errors
        print("Preview setting changed to False as not detected any screen")  # feedback is printed to terminal

    # evaluating and modifying settings due to HW reality
    if rpi_zero:                                      # case the used board is Rpi Zero or Zero2
        rendering = False                             # rendering is changed to False
        print("Rendering setting changed to False as Rpi Zero or Zero2")  # feedback is printed to terminal

    # evaluating the settings priority
    if local_control:                                 # case the local_control is set Ture
        if not start_now:                             # case start_sow is set False
            start_now = True                          # start_now is changed to True
            print("Start_now changed to True as local_control is set True")  # feedback is printed to terminal
        if days > 1:                                  # case the set days are > 1
            days = 1                                  # days is set to one
    if start_now:                                     # case start_sow is set True
        days = 1                                      # only a single period (day) is considered
    
    GPIO, upper_btn, lower_btn, disp = set_gpio(display)  # calls the function to set gpio
    
    # calls to the function to set the camera
    picam2, camera_started, error = set_camera(camera_w, camera_h, rotate_180, hdr, autofocus, focus_dist_m, preview)  
    if error!=0:                                      # case camera setting raises errors
        return variables, error                       # error is returned
    
    # variables are added to the variables dictionary (key is the string of the variable name)
    variables['rpi_zero'] = rpi_zero
    variables['picam2'] = picam2
    variables['camera_started'] = camera_started
    variables['GPIO'] = GPIO
    
    variables['upper_btn'] = upper_btn
    variables['lower_btn'] = lower_btn
    variables['disp'] = disp
    
    variables['preview'] = preview
    variables['erase_pics'] = erase_pics
    variables['erase_movies'] = erase_movies
    
    variables['local_control'] =local_control
    variables['start_now'] = start_now
    variables['period_hhmm'] = period_hhmm
    variables['start_hhmm'] = start_hhmm
    variables['end_hhmm'] =end_hhmm
    variables['interval_s'] = interval_s
    variables['days'] = days
    
    variables['rendering'] = rendering
    variables['fix_movie_t'] = fix_movie_t
    variables['movie_time_s'] = movie_time_s
    variables['fps'] = fps
    variables['overlay_fps'] = overlay_fps
    variables['overlay_text'] = overlay_text
    
    variables['camera_w'] = camera_w
    variables['camera_h'] = camera_h
    variables['hdr'] = hdr
    variables['autofocus'] = autofocus
    variables['focus_dist_m'] = focus_dist_m
    variables['lux_check'] = lux_check
    variables['lux_threshold'] = lux_threshold
    variables['date_folder'] = date_folder
    variables['folder'] = folder
    variables['parent_folder'] = parent_folder
    variables['pic_name'] = pic_name
    variables['pic_format'] = pic_format
    variables['rotate_180'] = rotate_180
    
    variables['display'] = display
    variables['modified_disp'] = modified_disp
    variables['disp_preview'] = disp_preview
    variables['disp_image'] = disp_image
    variables['disp_bright'] = disp_bright
    
    return variables, error                           # error code is returned
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

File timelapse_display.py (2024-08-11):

#!/usr/bin/python
# coding: utf-8

"""
#############################################################################################################
#  Andrea Favero 11 August 2024, Timelaps application
#############################################################################################################
"""


from PIL import Image, ImageDraw, ImageFont  # classes from PIL for image manipulation
import ST7789                                # library for the TFT display with ST7789 driver 
import os.path, pathlib, json                # library for the json parameter parsing for the display
from timelapse_pigpiod import pigpiod as pigpiod # start the pigpiod server
import pigpio                                # lightweight library for PWM (it requires pigpiod (daemon) running



class Display:
    def __init__(self):
        """ Imports and set the display.
            (mini pi tft 240x240 colortft add on forr Rspberry Pi, ca 5€ from Aliexpress)."""
                
        folder = pathlib.Path().resolve()                             # active folder   
        fname = os.path.join(folder,'settings.txt')                   # folder and file name for the settings
#         print(fname)
        if os.path.exists(fname):                                     # case the settings file exists
            with open(fname, "r") as f:                               # settings file is opened in reading mode
                settings = json.load(f)                               # json file is parsed to a local dict variable
            try:
                disp_rotation = int(settings['disp_rotation'])        # display rotation (allowed 0, 90 180 and 270)
                disp_bright = int(settings['disp_bright'])           # display brightness (allowed 0 to 100)
                disp_bright == 10 if disp_bright < 0 else disp_bright    # display brightness min value set to 10
                disp_bright == 100 if disp_bright > 100 else disp_bright # display brightness max value set to 100
                disp_width = int(settings['disp_width'])              # display width, in pixels
                disp_height = int(settings['disp_height'])            # display height, in pixels
                disp_offsetL = int(settings['disp_offsetL'])          # Display offset on width, in pixels, Left if negative
                disp_offsetT = int(settings['disp_offsetT'])          # Display offset on height, in pixels, Top if negative
            except:
                print('Error on converting imported parameters to int') # feedback is printed to the terminal
        else:                                                         # case the settings file does not exists, or name differs
            print('Could not find the file: ', fname)                 # feedback is printed to the terminal 

        
        self.disp = ST7789.ST7789(port=0, cs=0,                       # SPI and Chip Selection                  
                            dc=25, backlight=22,                      # GPIO pins used for the SPI and backlight control
                            width=disp_width,            #(AF 240)    # see note above for width and height !!!
                            height=disp_height,          #(AF 240)    # see note above for width and height !!!                         
                            offset_left=disp_offsetL,    #(AF 0)      # see note above for offset  !!!
                            offset_top= disp_offsetT,    #(AF 0)      # see note above for offset  !!!
                            rotation=disp_rotation,                   # image orientation
                            invert=True, spi_speed_hz=10000000)       # image invertion, and SPI     
        
        self.disp.set_backlight(0)            # display backlight is set off
        self.disp_w = self.disp.width         # display width, retrieved by display setting
        self.disp_h = self.disp.height        # display height, retrieved by display setting
        disp_img = Image.new('RGB', (self.disp_w, self.disp_h),color=(0, 0, 0))   # display image generation, full black
        self.disp.display(disp_img)           # image is displayed
        
        self.pi = pigpio.pi()                 # object for the pigpio class
        self.backlight = 18                   # GPIO to "jumper" with the GPIO22 at display or Rpi GPIO
        self.freq = 20000                     # frequency for the PWM


        
    def display_image(self, image):
        self.disp.display(image)


    def set_backlight(self, value):
        """Set the backlight on/off."""
        self.disp.set_backlight(value)
        if value == 0:
            self.dimm_backlight(0)




    def dimm_backlight(self, value):
        """Set the backlight to PWM value"""
        self.disp.set_backlight(0)
        self.pi.hardware_PWM(self.backlight, self.freq, value*10000 )





    def clean_display(self):
        """ Cleans the display by settings all pixels to black."""
        
        disp_img = Image.new('RGB', (self.disp_w, self.disp_h), color=(0, 0, 0))  # full black screen as new image
        self.disp.display(disp_img)                                               # display is shown to display
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

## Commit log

2023-11-26 Rev 0.2 (solved bugs)
    [timelapse.py]
2024-02-07 Ver 0.2 corrected bug
    [timelapse.py]
2024-08-07 V0.3 power outage
    Prevents images from being overwritten after power outage (if settings "date_folder" : "False" and "erase_pics" : "False")
    [timelapse.py]
2024-08-11 V0.4 Power outage and min_lux control
    Solved a couple of bugs from V0.3 (power outage)
    Added a control to only shoot if the estimated Lux by the camera is above a Threshold. This control is based on two variables at __main__ top part (lux_check, min_lux_threshold)
    [timelapse.py, timelapse_display.py]
2024-08-11 V0.4 Power outage and min_lux control
    Solved a couple of bugs from V0.3 (power outage).
    Added a control to only shoot if the estimated Lux by the camera is above a Threshold. This control is based on two variables at __main__ top part (lux_check, min_lux_threshold).
    [timelapse.py]
2024-08-25 Rev 0.5 (recovery rom outage when start_now)
    Extended the recovery from power outage function to when the start_now is set True.
    The variables to condition the shooting to illuminance have been added to the settings.txt file.
    Some minor inprovements
2024-08-30 Rev 0.6 (fixed a bug)
    Solved bug when start_now and not lux_check
    [timelapse.py]
2024-10-14 Solved bug
    After power outage, solved the pictures being overwritten
    [timelapse.py]
